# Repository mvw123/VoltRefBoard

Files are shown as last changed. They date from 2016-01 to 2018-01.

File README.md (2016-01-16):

Voltage Reference Board
=========================

Reference board for voltage calibration. 
Design files are in Eagle v 6.5.0 (free version).
The design is 5cm x 5cm to allow low cost manufacture. 

CAD B - Work in progress
========================

Cost reduced board
PCB setup to use the sick of beige acrylic case.

CAD A - [PCB ordered]
=====================

Board not used, 
PCB fabrication ordered from OSH park. 
Need to setup parts for ordering. 
2.5v and 5.0v voltage reference source from a 9v battery or from an external power source.
The use of >10V is slightly more accurate when using these precision reference ICs. 

MVW
www.guvvy.co.uk

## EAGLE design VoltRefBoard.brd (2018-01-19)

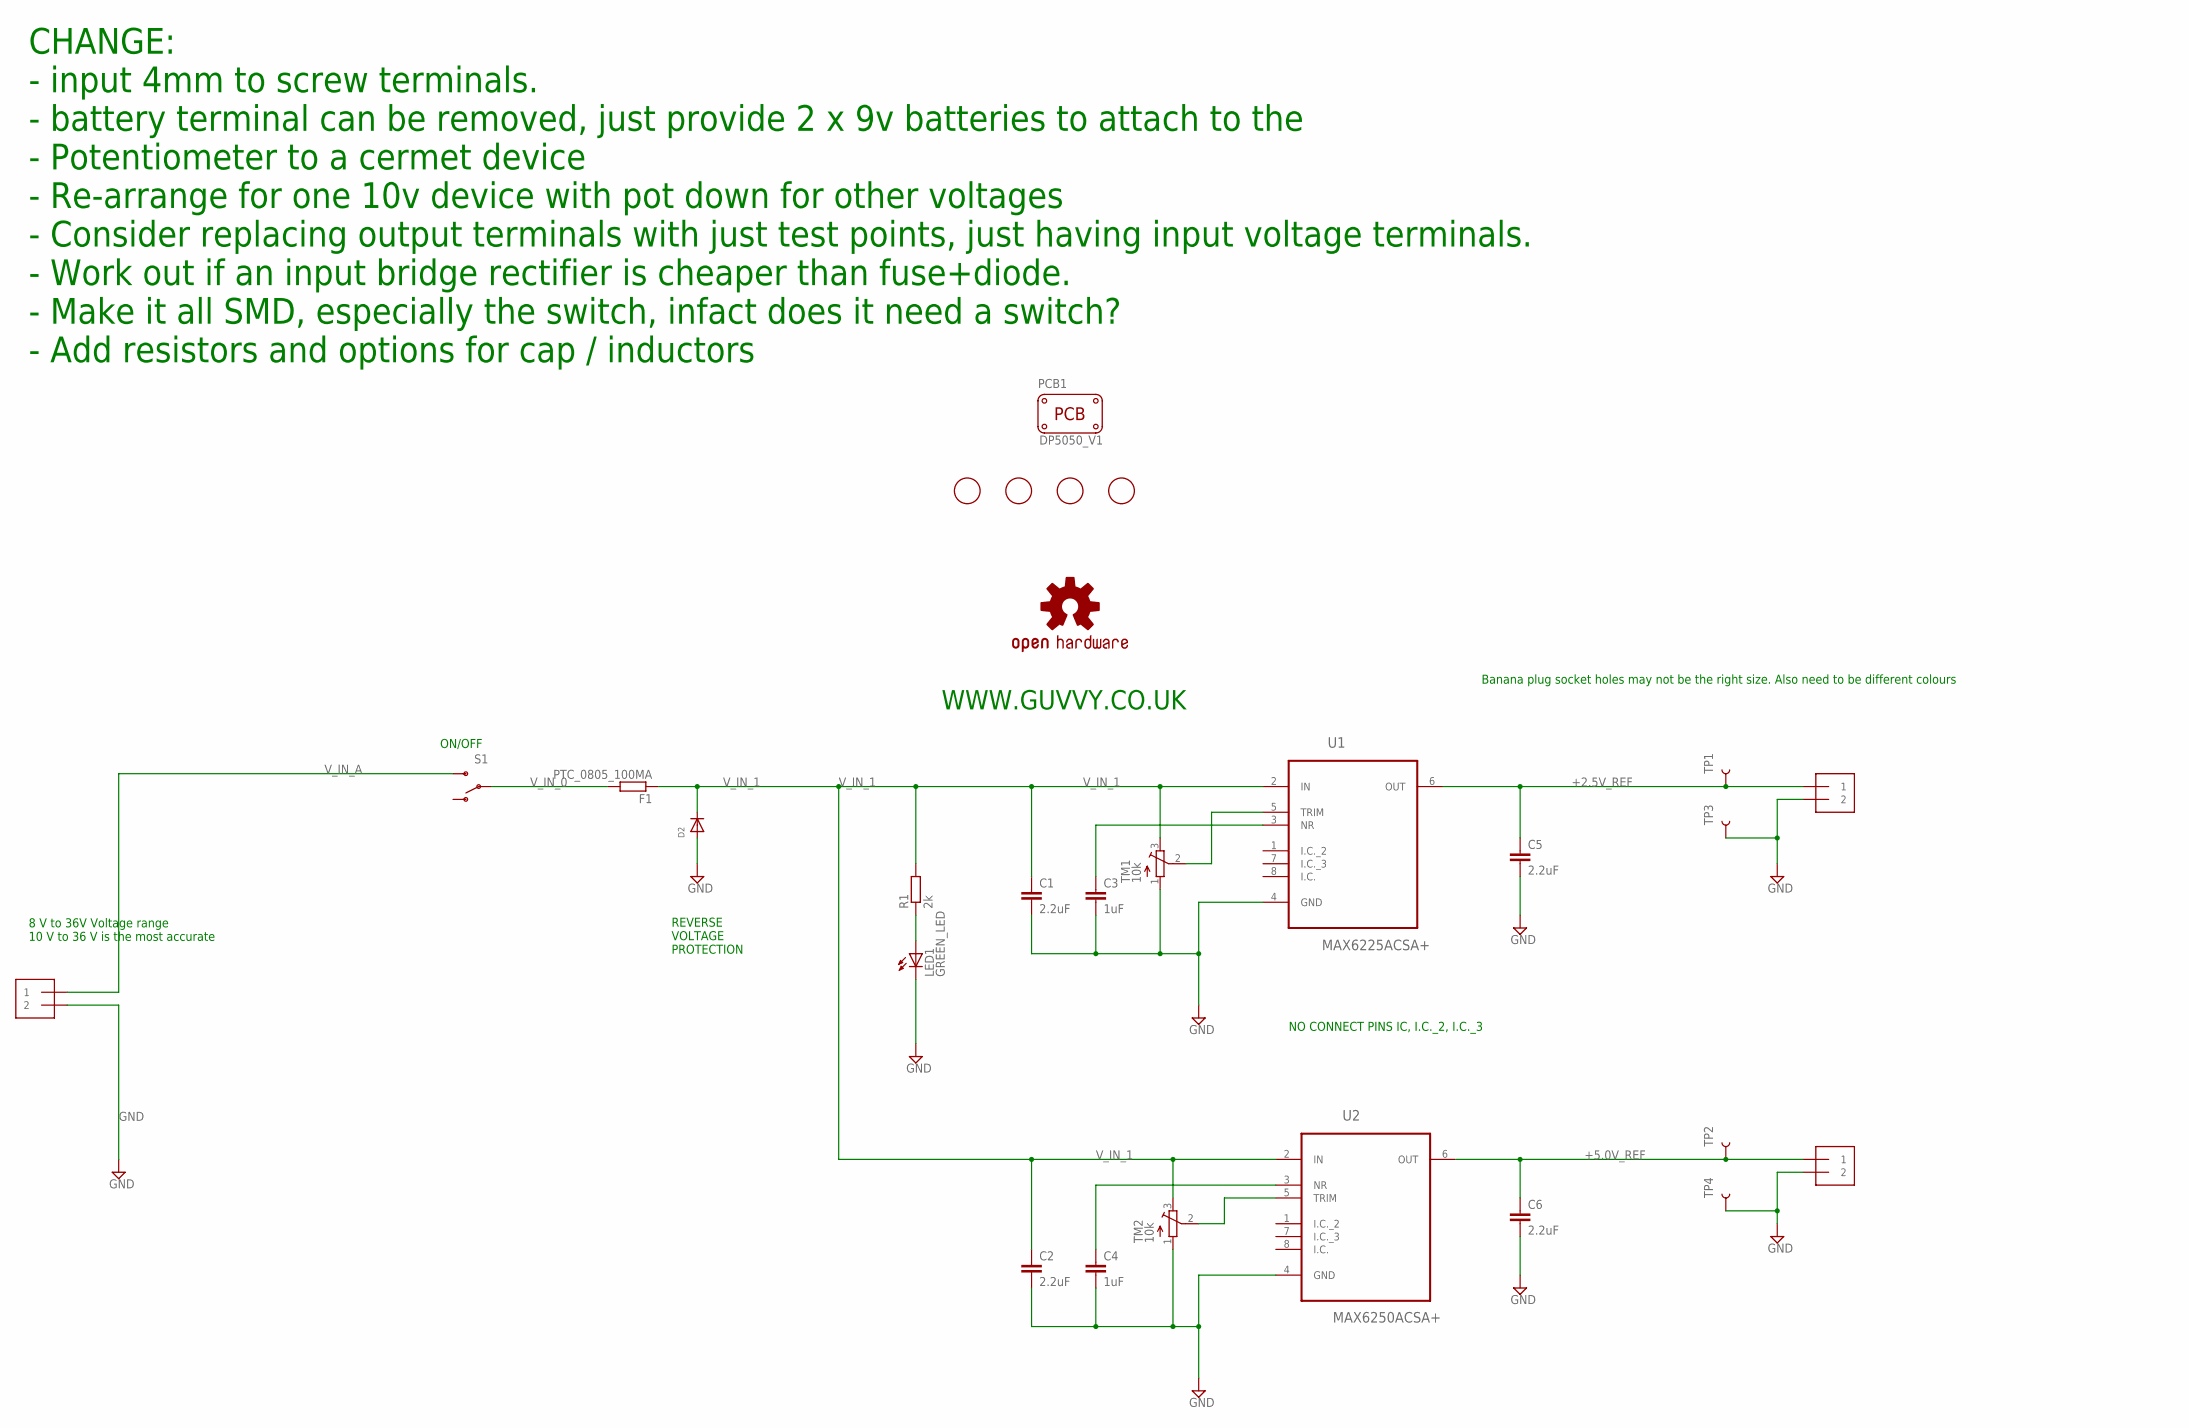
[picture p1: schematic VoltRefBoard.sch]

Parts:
C1, C2, C5, C6: 2.2uF; C0805
C3, C4: 1uF; C0805
D2: DIODESOD-323F; SOD-323F; MPN PMEG3010EJ,115
F1: PTC_0805_100MA; R0805; MPN MINISMDC110F/24-2
J1, J2, J6: 1X2-3.5MM
LED1: GREEN_LED; P-LCC-2; MPN LGT67K-H2K1-24-Z
LOGO1: OSHW-LOGOL; OSHW-LOGO-L
PCB1: PCB_DP_SQUARE-5X5; DP5050_V1
R1: 2k; R0805
S1: SWITCH-SPDT-SMD-A; SWITCH-SPST-SMD-A
TM1, TM2: 10k; TC33X; MPN TS53YJ103MR10
TP1, TP2, TP3, TP4: TP_1MM_TH"; TP_1MM_TH; MPN TEST-3
U1: MAX6225ACSA+; SOIC127P600X175-8N; MPN MAX6225ACSA+.
U2: MAX6250ACSA+; SOIC127P600X175-8N; MPN MAX6250ACSA+.
U$1, U$2, U$3, U$4: FIDUCIAL; FIDUCIAL_1MM

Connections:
+2.5V_REF: C5.1, J1.1, TP1.P$1, U1.6 (OUT)
+5.0V_REF: C6.1, J2.1, TP2.P$1, U2.6 (OUT)
GND: C1.2, C2.2, C3.2, C4.2, C5.2, C6.2, D2.A, J1.2, J2.2, J6.2, LED1.C, TM1.1 (A), TM2.1 (A), TP3.P$1, TP4.P$1, U1.4 (GND), U2.4 (GND)
unnamed: TM2.2 (S), U2.5 (TRIM)
unnamed: TM1.2 (S), U1.5 (TRIM)
unnamed: C4.1, U2.3 (NR)
unnamed: C3.1, U1.3 (NR)
unnamed: LED1.A, R1.1
V_IN_0: F1.2, S1.2
V_IN_1: C1.1, C2.1, D2.C, F1.1, R1.2, TM1.3 (E), TM2.3 (E), U1.2 (IN), U2.2 (IN)
V_IN_A: J6.1, S1.3 (S)

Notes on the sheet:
8 V to 36V Voltage range 10 V to 36 V is the most accurate
NO CONNECT PINS IC, I.C._2, I.C._3
REVERSE VOLTAGE PROTECTION
ON/OFF
WWW.GUVVY.CO.UK
Banana plug socket holes may not be the right size. Also need to be different colours
CHANGE: - input 4mm to screw terminals. - battery terminal can be removed, just provide 2 x 9v batteries to attach to the - Potentiometer to a cermet device - Re-arrange for one 10v device with pot down for other voltages - Consider replacing output terminals with just test points, just having inpu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

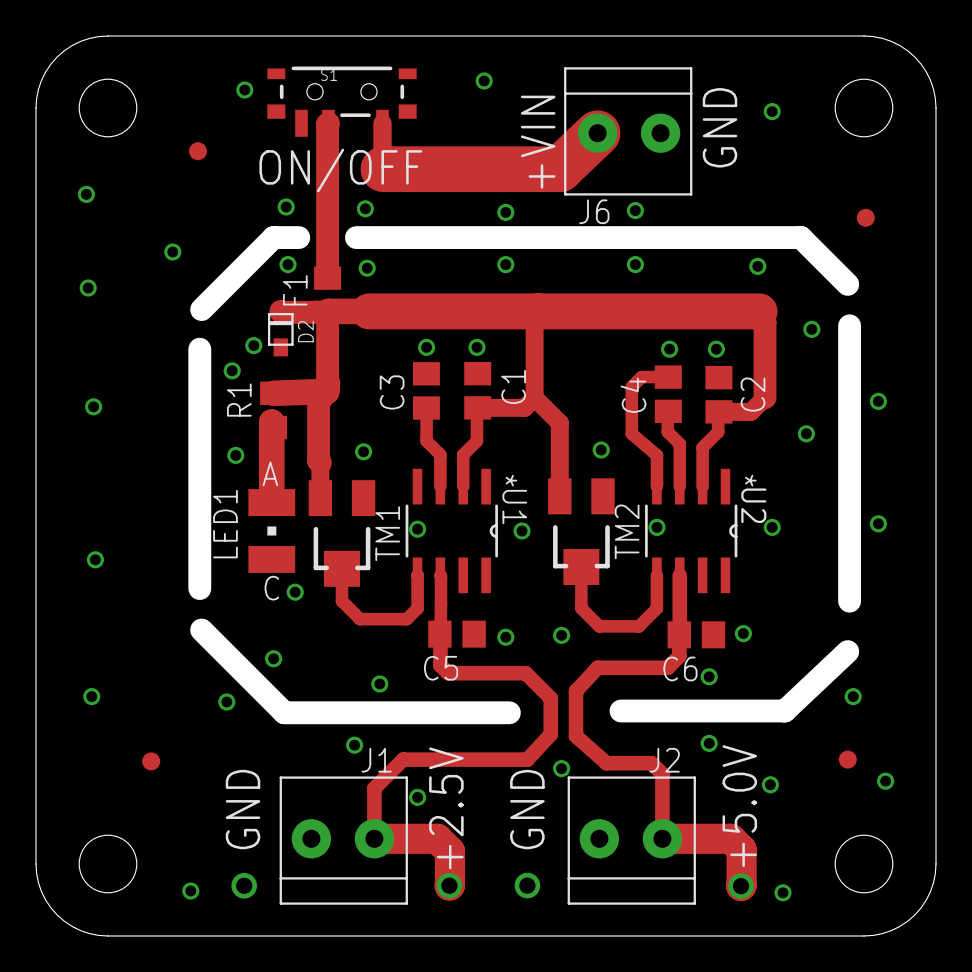
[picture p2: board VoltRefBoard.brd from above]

Board: 2 copper layers, 50.0 x 50.0 mm, 28 parts (1 on the bottom side), 11 nets.

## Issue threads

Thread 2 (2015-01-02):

Bannanananana socket hole may not be correct size, also various hole sizes are used

mvw123, 2015-01-02:
Bannanananana socket hole may not be correct size, also various hole sizes are used
hole appears to be 3.8mm
M3, M4 M6 are used .
need to check the cost / size advantages

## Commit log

2014-12-27 CAD A PCB released for manufacture
    CAD A PCB released for manufacture
    Requires updates to the part numbers for purchasing
    [VoltCalBoard.brd, VoltCalBoard.sch]
2014-12-27 Updated file names
    Updated file names and slightly amended the readme file
    [VoltRefBoard.brd, VoltRefBoard.sch]
2015-02-15 Latest commits
    [VoltRefBoard.brd, VoltRefBoard.sch]
2016-01-16 Added the 5x5 pcbs from sick of beige
    Added the 5x5 pcbs from sick of beige and added cost down notes to the
    schematic to make it cheap to manufacture
    [VoltRefBoard.brd, VoltRefBoard.sch]
2016-01-26 adding latest updates
    adding latest updates
    [VoltRefBoard.brd, VoltRefBoard.sch]
2018-01-19 minor updates
    [VoltRefBoard.brd, VoltRefBoard.sch]

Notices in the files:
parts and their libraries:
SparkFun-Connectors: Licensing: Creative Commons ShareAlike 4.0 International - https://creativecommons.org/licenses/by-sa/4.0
